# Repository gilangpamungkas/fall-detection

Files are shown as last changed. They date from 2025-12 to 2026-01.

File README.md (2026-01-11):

# 🛡️ mmWave-Based Indoor Fall Detection System  
**CASA0016 – Making, Designing & Building Connected Sensor Systems**

An edge-based, privacy-preserving indoor fall detection prototype using a 60 GHz mmWave radar sensor, MQTT communication, and real-time WhatsApp alerts.

---

## 📌 Project Overview

Falls are a major cause of injury among older adults, particularly in indoor environments where rapid detection is critical.  
This project designs, builds, and evaluates an **indoor fall detection prototype** using a **60 GHz mmWave radar sensor** integrated with an **ESP32-based microcontroller**.

Unlike vision-based approaches, the system enables **continuous, non-contact monitoring** while preserving user privacy. Fall detection is performed locally using embedded radar firmware, with **edge-based event handling** triggering both local alerts and remote notifications.

⚠️ **Disclaimer:** This prototype is not a medical device and is intended for educational and exploratory purposes only.

---

## 🧠 Key Capabilities

- Privacy-preserving, non-contact sensing  
- Edge-based fall detection (no raw motion data transmitted)  
- Immediate local alerts (RGB LED + buzzer)  
- Remote notifications via WhatsApp  
- Lightweight IoT communication using MQTT  
- Designed for continuous indoor deployment  

---

## 🏗️ System Architecture

The system follows an **edge-centric, event-driven architecture**:

<p align="center">
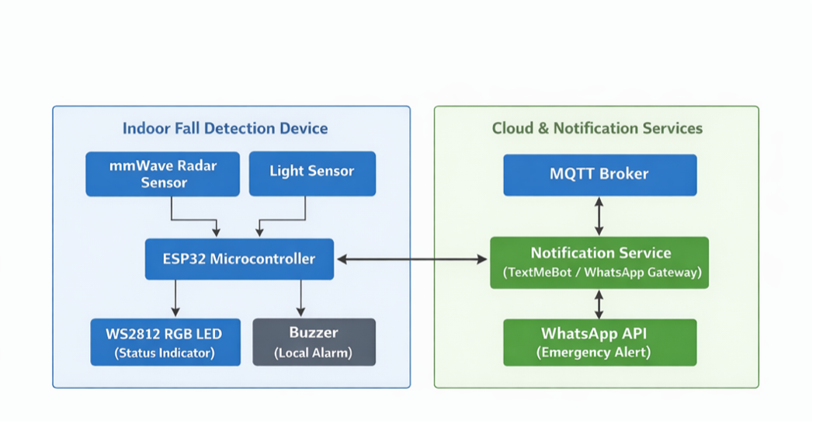
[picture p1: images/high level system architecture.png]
Figure 1. high level system architecture
  
</p>

<p align="center"><em>Figure 1. high level system architecture</em></p>

### 1️⃣ Sensing & Classification (Edge)
- 60 GHz mmWave radar performs embedded fall detection
- Abstracted states: `no presence`, `presence`, `fall`
- No transmission of raw sensor data

### 2️⃣ Local Feedback
- RGB LED indicates system state
- Audible buzzer activates on confirmed fall events

### 3️⃣ Communication & Alerts
- MQTT publishes lightweight status messages
- WhatsApp alerts sent via HTTP API
- NTP time synchronisation for alert timestamps
- One-time alert logic prevents notification flooding

---

## 🔩 Hardware Components

| Component | Description |
|---|---|
| MR60FDA2 | 60 GHz mmWave fall detection module |
| XIAO ESP32C6 | Embedded microcontroller with Wi-Fi |
| RGB LED (WS2812B) | Visual system state indication |
| Grove Buzzer | Audible fall alert |
| BH1750 | Ambient light sensor (contextual only) |
| Power Supply | 5 V USB (always-on indoor deployment) |

**Mounting:** Ceiling-mounted at ~2.5 m in a residential room.

<p align="center">
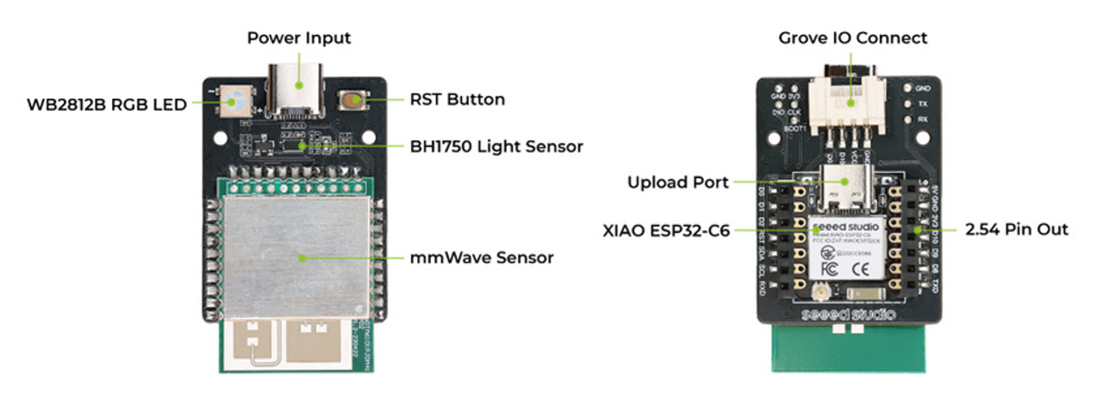
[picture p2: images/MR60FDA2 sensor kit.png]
Figure 2. MR60FDA2 sensor kit
  
</p>

<p align="center"><em>Figure 2. MR60FDA2 sensor kit</em></p>

---

## 🧱 Physical Implementation

**Figure:** Physical implementation of the prototype  
- **(a)** Fusion 360 enclosure design  
- **(b)** 3D-printed enclosure with device placement  
- **(c)** Grove buzzer for audible alerts  

<p align="center">
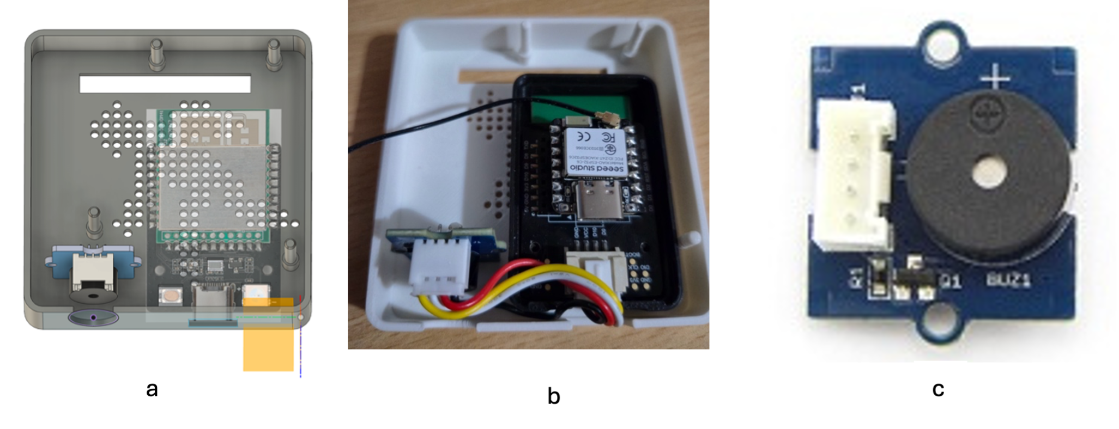
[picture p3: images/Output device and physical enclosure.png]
Figure 3. Physical implementation of the prototype: (a) Fusion 360 enclosure design, (b) 3D-printed enclosure with device placement, (c) Grove buzzer for audible alerts
  
</p>

<p align="center"><em>Figure 3. Physical implementation of the prototype: (a) Fusion 360 enclosure design, (b) 3D-printed enclosure with device placement, (c) Grove buzzer for audible alerts</em></p>

📂 Fusion 360 files of enclosure are available in `/enclosure/`.

---

## 💻 Software Stack

- Arduino IDE  
- Seeed Arduino mmWave Library  
- Adafruit NeoPixel Library  
- WiFi & PubSubClient (MQTT)  
- HTTPClient (WhatsApp API)  
- NTP time synchronisation  

Core logic is implemented in a **single Arduino sketch** (/fall_detection_v2.ino) for clarity and reproducibility.

---

## 🔁 Reproducibility Guide

### 🔌 Wiring

Most sensing and processing components are **integrated within the MR60FDA2 kit**.  
External wiring is limited to:

- Grove Buzzer  
- Power supply (USB)

<p align="center">
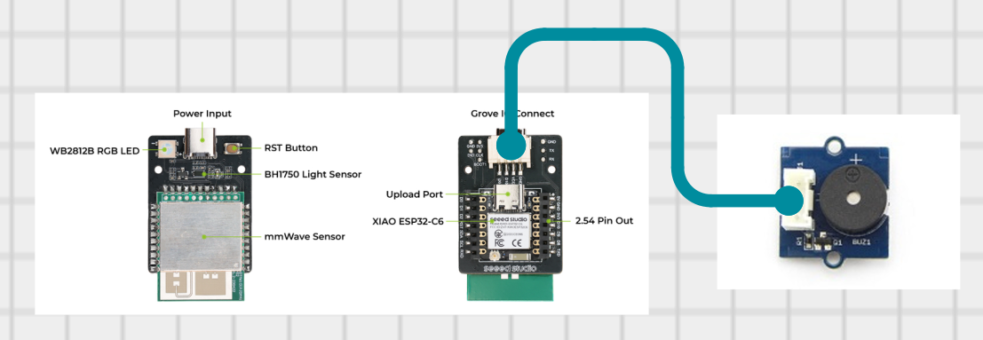
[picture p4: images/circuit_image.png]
Figure 4. Wiring Diagram
  
</p>

<p align="center"><em>Figure 4. Wiring Diagram</em></p>

---

### 📍 Pin Mapping

| Component | Pin |
|---|-----|
| Grove Buzzer | GPIO (external) |
| RGB LED | Integrated |
| mmWave Radar | Integrated |
| BH1750 | Integrated |

---

### ⚙️ Installation Parameters

The following parameters are configured based on the official MR60FDA2 mmWave sensor guidelines and directly influence fall detection behaviour:

| Parameter | Typical Value | Description |
|---|---|---|
| Mounting height | ~2.5 m | Recommended ceiling-mounted height for reliable top-down fall detection coverage |
| Detection threshold | Configurable | Vertical displacement threshold used by the embedded fall detection firmware |
| Sensitivity | Medium | Controls radar responsiveness to motion intensity |
| Alert mode | One-time per fall | Prevents repeated notifications from a single detected fall event |

These parameters were tuned to balance detection reliability and false-positive reduction in a residential indoor environment.  
See: *Getting Started with MR60FDA2 mmWave Kit* (Seeed Studio, 2025).

---

### ▶️ Setup Order

1. Mount the device on the ceiling at approximately 2.5 m.
2. Power the system via a 5 V USB supply.
3. Configure Wi-Fi credentials in the Arduino sketch.
4. Configure MQTT broker address and topic settings.
5. Configure WhatsApp notification parameters (TextMeBot API key and chat ID).
6. Set installation parameters (mounting height, detection threshold, sensitivity).
7. Upload the firmware to the ESP32C6.
8. Deploy the system and observe LED state indicators.
9. Test fall detection scenarios and verify local and remote alerts.

---

### 📲 WhatsApp Alert Configuration

Remote fall alerts are delivered using the **TextMeBot WhatsApp API**, a lightweight HTTP-based service that enables WhatsApp message delivery from embedded devices without requiring a dedicated messaging server.

When a fall event is detected, the ESP32 sends an HTTP GET request to the TextMeBot API endpoint, which forwards the alert message to a configured WhatsApp number.

#### 🔑 API Key and Recipient Configuration

To enable WhatsApp notifications, users must obtain a personal **TextMeBot API key** and associate it with their WhatsApp number following the instructions provided by the service. These credentials are user-specific and are therefore not included in this repository.

The following parameters must be configured directly in the Arduino sketch (`.ino` file):

```cpp
// --- WhatsApp (TextMeBot) Configuration ---
// Replace with your own API key and recipient number
const char* TEXTMEBOT_API_KEY = "YOUR_API_KEY";
const char* TEXTMEBOT_RECIPIENT = "+441234567890";  // WhatsApp number including country code
🌐 Message Delivery Mechanism
When a fall is detected, the firmware constructs and sends an HTTP request of the following form:

arduino
Copy code
https://api.textmebot.com/web_send.php?apikey=YOUR_API_KEY&recipient=PHONE_NUMBER&text=MESSAGE
The request is sent using the ESP32 HTTP client library. Message content is URL-encoded to ensure safe transmission. A timestamp obtained via NTP synchronisation is appended to the message to provide temporal context.

🔒 Rate Limiting and Safety
To prevent alert flooding, the system implements a one-time notification mechanism, ensuring that only a single WhatsApp alert is sent per detected fall event until the system state resets. This behaviour improves usability and reflects realistic deployment requirements for indoor safety monitoring systems.
```
---

## 🧪 Evaluation Summary

Testing was conducted in a **room-scale indoor environment** under three scenarios:

1. No occupant present  
2. Normal movement (walking, standing, sitting)  
3. Simulated fall events  

### Key Observations
- Immediate fall detection and alert triggering  
- Stable MQTT publishing  
- No false positives during normal movement  
- Sensitivity to threshold configuration  
- Limited discrimination between falls and slow postural transitions  

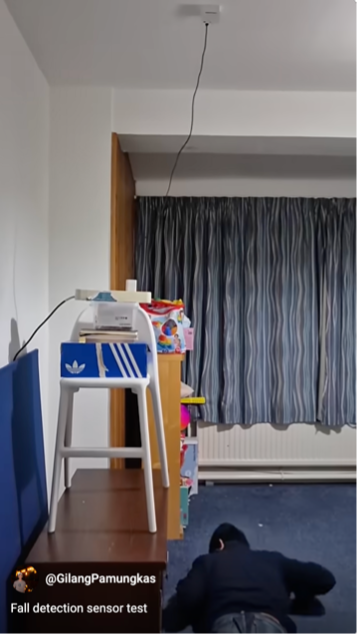
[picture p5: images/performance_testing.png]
Demo Video (https://www.youtube.com/shorts/zDeqPK8EPvs)
🚀 See the project come to life! Watch the demo on Youtube here: 

---

## 🔍 Reflection & Limitations

- Detection behaviour is sensitive to threshold configuration  
- Proprietary radar firmware limits access to raw motion data  
- The system cannot reliably distinguish intentional lying from real falls  
- Design constraints reflect real-world IoT deployment trade-offs  

The project intentionally focuses on **system-level design**, prioritising:
- deployment realism  
- privacy preservation  
- robustness  
- reproducibility  

---

## 🚀 Future Work

- Learning-based fall classification using temporal motion features  
- Access to raw mmWave data for improved semantic accuracy  
- Multi-sensor fusion (e.g. inertial validation)  
- Battery-powered operation  
- Multi-room monitoring dashboard  

---

## 📂 Repository Structure

```
fall-detection/
├── enclosure/ # Enclosure design files (Fusion 360 & STL)
├── images/ # Photos and diagrams used in README
├── README.md # Main project documentation
├── arduino_secrets_template.h # Template for API keys and sensitive config
├── fall_detection_v2.ino # Main Arduino firmware sketch
├── LICENSE.txt # MIT License

```
---

## 📄 Coursework Context

- **Module:** CASA0016 – Making, Designing & Building Connected Sensor Systems  
- **Institution:** UCL Centre for Advanced Spatial Analysis, MSc Connected Environments 
- **Author:** Gilang Pamungkas  
- **Date:** December 2025  

📘 The full technical report accompanies this repository.

---

## 📚 References

Huh, H., Jeong, I., Lee, A., Lee, S. and Shin, Y.-S. (2025). Leveraging falling acceleration and body part clustering for physics-based human fall detection with millimeter wave radar. *Engineering Applications of Artificial Intelligence*, 159, 111500.

Seeed Studio (2025). *Getting Started with MR60FDA2 mmWave Kit*. Available at: https://wiki.seeedstudio.com/getting_started_with_mr60fda2_mmwave_kit (Accessed: 30 December 2025).

Shi, W., Cao, J., Zhang, Q., Li, Y. and Xu, L. (2016). Edge computing: Vision and challenges. *IEEE Internet of Things Journal*, 3(5), pp. 637–646.

Wang, Z., Yan, G., Yang, X., Zhao, X., Li, X. and Chai, M. (2023). Research on the fall detection method based on millimeter-wave radar. In: *Proceedings of the 5th International Conference on Intelligent Control, Measurement and Signal Processing (ICMSP 2023)*, pp. 139–142.

World Health Organization (2007). *WHO Global Report on Falls Prevention in Older Age*. Geneva: World Health Organization.

World Health Organization (2023). *Ageing and Health*. Available at: https://www.who.int/news-room/fact-sheets/detail/ageing-and-health (Accessed: 24 December 2025).

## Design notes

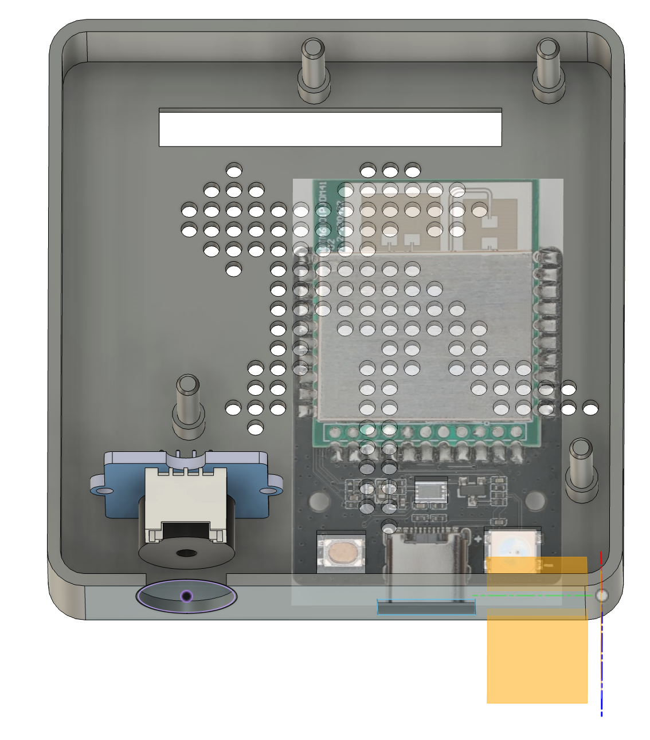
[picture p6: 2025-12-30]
images/sensor design.png

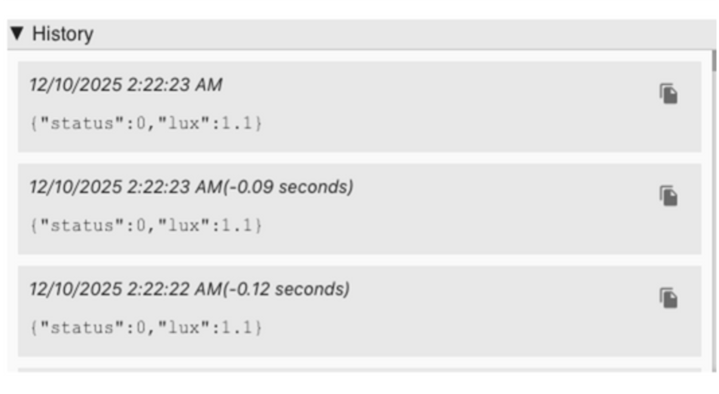
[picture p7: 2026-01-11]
images/sample mqtt messages.png

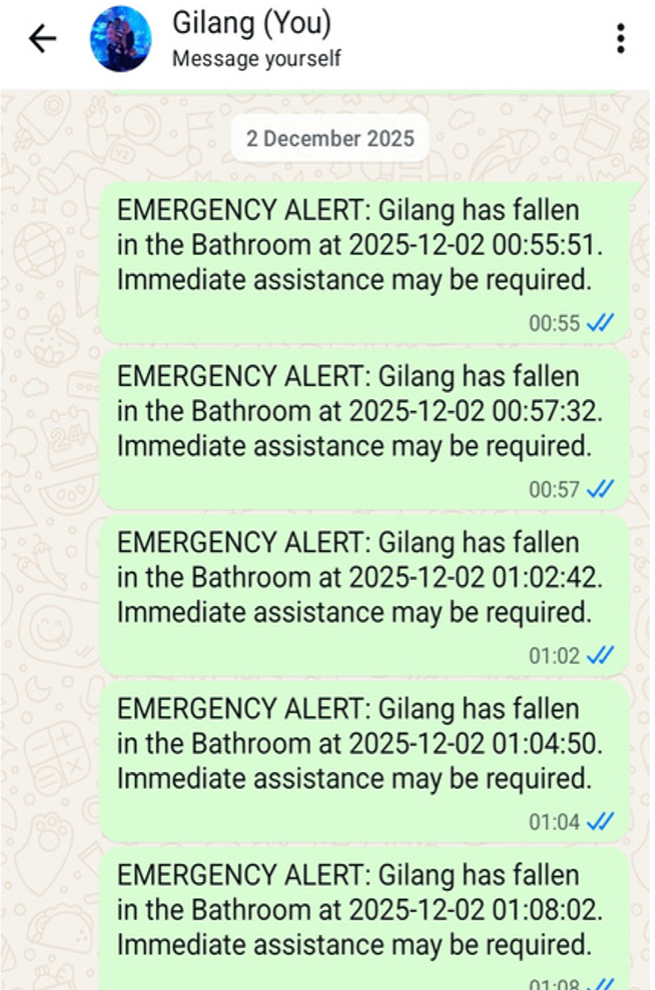
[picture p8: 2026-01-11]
images/sample of whatsapp alert.png

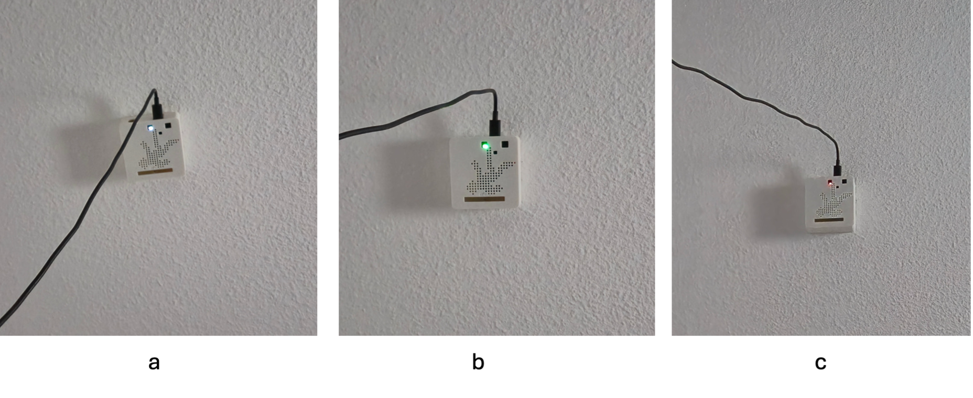
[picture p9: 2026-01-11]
images/LED colour representation.png

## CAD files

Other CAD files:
enclosure/enclosure_bottom_side.f3d
enclosure/enclosure_top_side.f3d

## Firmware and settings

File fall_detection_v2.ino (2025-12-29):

/**
 * CASA0016 — mmWave-Based Indoor Fall Detection System
 * University College London | Making, Designing & Building Connected Sensor Systems
 *
 * This sketch implements an edge-based indoor fall detection prototype using:
 * - MR60FDA2 60 GHz mmWave radar sensor (proprietary fall detection firmware)
 * - Seeed Studio XIAO ESP32C6 microcontroller
 * - WS2812 RGB LED and piezo buzzer for local feedback
 * - MQTT for lightweight status publishing
 * - WhatsApp alerts via TextMeBot HTTP API
 *
 * Reproducibility & Configuration
 * -------------------------------
 * This project requires a user-provided configuration file:
 *   arduino_secrets.h
 *
 * A template file:
 *   arduino_secrets_template.h
 * is included in this repository. To reproduce the system:
 * 1. Copy the template file
 * 2. Rename it to arduino_secrets.h
 * 3. Populate it with your own credentials (Wi-Fi, MQTT, API keys)
 *
 * IMPORTANT:
 * - Do NOT commit arduino_secrets.h to version control
 * - This prototype is for academic and exploratory use only
 * - It is NOT a medical or safety-certified device
 *
 * Design Notes
 * ------------
 * - Fall detection logic runs in closed, vendor-provided firmware
 * - This sketch reads high-level detection states only
 * - Alert logic is event-driven and rate-limited (one alert per fall)
 */

#include <Arduino.h>
#include <Adafruit_NeoPixel.h>
#include <hp_BH1750.h>
#include "Seeed_Arduino_mmWave.h"

#include <WiFi.h>
#include <PubSubClient.h>
#include <HTTPClient.h>
#include <time.h>

#include "arduino_secrets.h"  // User-provided secrets (see template)

/* ============================= Network clients ============================= */
WiFiClient wifiClient;
PubSubClient client(wifiClient);

/* =============================== GPIO settings ============================= */
#define BUZZER_PIN D0
#define LIGHT_GPIO D0  // Kept unchanged (forced LOW in loop; BH1750 used for logging only)

/* =============================== MQTT settings ============================= */
String mqtt_topic = MQTT_TOPIC;   // from arduino_secrets.h
static const char* MQTT_CLIENT = MQTT_CLIENT_ID;

/* ============================ mmWave sensor config ========================== */
#ifdef ESP32
  #include <HardwareSerial.h>
  HardwareSerial mmwaveSerial(0);     // UART channel used by mmWave module (ESP32)
#else
  #define mmwaveSerial Serial1
#endif

SEEED_MR60FDA2 mmWave;

// Tuneable parameters (match physical installation)
uint32_t sensitivity = 15;            // Higher values can increase responsiveness (and false alarms)
float height = 2.5f;                  // Mount height (metres)
float threshold = 0.6f;               // Detection threshold (tune carefully)

// Returned radar parameters (optional debug)
float rect_XL, rect_XR, rect_ZF, rect_ZB;

/* ============================ Light sensor + LED ============================ */
hp_BH1750 BH1750;
Adafruit_NeoPixel pixels(1, D1, NEO_GRB + NEO_KHZ800);

/* ============================== System state =============================== */
typedef enum {
  EXIST_PEOPLE = 0,
  NO_PEOPLE    = 1,
  PEOPLE_FALL  = 2,
} MMMWAVE_STATUS;

MMMWAVE_STATUS status = NO_PEOPLE;
MMMWAVE_STATUS last_status = NO_PEOPLE;

float lux = 100.0f;
bool doingFallBuzz = false;

/* =============================== Wi-Fi helper ============================== */
/**
 * Connects to the first available Wi-Fi network listed in arduino_secrets.h.
 * Retries each SSID for ~10 seconds.
 */
void startWifi() {
  Serial.println("Starting WiFi...");

  WiFi.mode(WIFI_STA);
  WiFi.disconnect(true);
  delay(200);

  for (int i = 0; i < numNetworks; i++) {
    Serial.print("Trying SSID: ");
    Serial.println(ssids[i]);

    WiFi.begin(ssids[i], passwords[i]);
    const unsigned long startAttempt = millis();

    while (WiFi.status() != WL_CONNECTED && (millis() - startAttempt) < 10000) {
      Serial.print(".");
      delay(500);
    }

    if (WiFi.status() == WL_CONNECTED) {
      Serial.println("\nWiFi connected!");
      Serial.print("IP: ");
      Serial.println(WiFi.localIP());
      return;
    }

    Serial.println("\nFailed. Trying next...");
    WiFi.disconnect(true);
    delay(200);
  }

  Serial.println("Could not connect to any WiFi.");
}

/* =============================== MQTT helper =============================== */
/**
 * Connects/reconnects to MQTT broker using credentials from arduino_secrets.h.
 * Blocks until connected.
 */
void reconnectMQTT() {
  while (!client.connected()) {
    Serial.print("Connecting to MQTT... ");
    if (client.connect(MQTT_CLIENT, MQTT_USER, MQTT_PASS)) {
      Serial.println("connected.");
    } else {
      Serial.print("failed, rc=");
      Serial.print(client.state());
      Serial.println(" retrying in 5 seconds");
      delay(5000);
    }
  }
}

/* ============================ WhatsApp notification ========================= */
/**
 * Sends an alert message via TextMeBot (WhatsApp).
 * Secrets (recipient, API key, base URL, message prefix/suffix) live in arduino_secrets.h.
 */
void sendWhatsAppAlert() {
  if (WiFi.status() != WL_CONNECTED) {
    Serial.println("[WhatsApp] WiFi not connected!");
    return;
  }

  struct tm timeinfo;
  if (!getLocalTime(&timeinfo)) {
    Serial.println("[WhatsApp] Failed to obtain time!");
    return;
  }

  char timeString[40];
  strftime(timeString, sizeof(timeString), "%Y-%m-%d %H:%M:%S", &timeinfo);

  // Build URL-encoded message using configurable prefix/suffix
  String message = WHATSAPP_MESSAGE_PREFIX;
  message += String(timeString);
  message += WHATSAPP_MESSAGE_SUFFIX;

  // Minimal extra encoding (kept consistent with your original behaviour)
  message.replace(" ", "%20");
  message.replace(":", "%3A");

  // Build request URL from secrets
  String url = String(TEXTMEBOT_BASE_URL);
  url += "recipient=" + String(TEXTMEBOT_RECIPIENT);
  url += "&apikey=" + String(TEXTMEBOT_APIKEY);
  url += "&text=" + message;

  Serial.println("[WhatsApp] Sending alert...");
  // Note: printing the full URL may reveal secrets in Serial logs.
  // Uncomment only when debugging locally.
  // Serial.println(url);

  HTTPClient http;
  http.begin(url);
  const int httpCode = http.GET();

  if (httpCode > 0) {
    Serial.printf("[WhatsApp] Response: %d\n", httpCode);
    Serial.println(http.getString());
  } else {
    Serial.printf("[WhatsApp] Error: %s\n", http.errorToString(httpCode).c_str());
  }

  http.end();
}

/* =========================== Local feedback helpers ========================= */
void updateLedForStatus(MMMWAVE_STATUS s) {
  if (s == NO_PEOPLE)    pixels.setPixelColor(0, pixels.Color(0, 0, 255));   // Blue
  if (s == EXIST_PEOPLE) pixels.setPixelColor(0, pixels.Color(0, 255, 0));   // Green
  if (s == PEOPLE_FALL)  pixels.setPixelColor(0, pixels.Color(255, 0, 0));   // Red
  pixels.show();
}

void startFallBuzzer() {
  tone(BUZZER_PIN, 700);
  doingFallBuzz = true;
}

void stopFallBuzzer() {
  noTone(BUZZER_PIN);
  doingFallBuzz = false;
}

/* =================================== Setup ================================== */
void setup() {
  Serial.begin(115200);

  // ---- mmWave module init + configuration ----
  mmWave.begin(&mmwaveSerial);
  mmWave.setUserLog(0);
  mmWave.setInstallationHeight(height);
  mmWave.setThreshold(threshold);
  mmWave.setSensitivity(sensitivity);
  mmWave.getRadarParameters(height, threshold, sensitivity, rect_XL, rect_XR, rect_ZF, rect_ZB);

  // ---- Buzzer ----
  pinMode(BUZZER_PIN, OUTPUT);
  noTone(BUZZER_PIN);

  // ---- Network ----
  startWifi();
  client.setServer(MQTT_SERVER, MQTT_PORT);
  reconnectMQTT();

  // ---- NTP time ----
  // Offsets (including daylight) are configured in arduino_secrets.h
  configTime(NTP_GMT_OFFSET_SEC, NTP_DAYLIGHT_OFFSET_SEC, "pool.ntp.org", "time.nist.gov");

  // ---- LED ----
  pixels.begin();
  pixels.clear();
  pixels.setBrightness(8);
  pixels.setPixelColor(0, pixels.Color(125, 125, 125));  // boot indicator
  pixels.show();

  // ---- BH1750 (context only) ----
  BH1750.begin(BH1750_TO_GROUND);
  BH1750.calibrateTiming();
  BH1750.start(BH1750_QUALITY_HIGH2, 254);

  // ---- LIGHT_GPIO ----
  pinMode(LIGHT_GPIO, OUTPUT);
}

/* ==================================== Loop ================================== */
void loop() {
  // Maintain connectivity
  if (WiFi.status() != WL_CONNECTED) startWifi();
  if (!client.connected()) reconnectMQTT();
  client.loop();

  // -------------------- Read mmWave abstracted states --------------------
  if (mmWave.update(100)) {
    bool is_human = false;
    bool is_fall = false;

    mmWave.getHuman(is_human);
    mmWave.getFall(is_fall);

    if (!is_human && !is_fall) status = NO_PEOPLE;
    else if (is_fall)          status = PEOPLE_FALL;
    else                       status = EXIST_PEOPLE;
  }

  // ---------------------------- Serial logging ---------------------------
  switch (status) {
    case NO_PEOPLE:    Serial.println("Waiting for people"); break;
    case EXIST_PEOPLE: Serial.println("PEOPLE detected");    break;
    case PEOPLE_FALL:  Serial.println("FALL detected");      break;
    default: break;
  }

  // ------------------ One-time WhatsApp alert per fall -------------------
  static bool fallAlertSent = false;
  if (status == PEOPLE_FALL && !fallAlertSent) {
    sendWhatsAppAlert();
    fallAlertSent = true;
  }
  if (status != PEOPLE_FALL) {
    fallAlertSent = false;
  }

  // ------------------ Update LED + buzzer on state change ----------------
  if (status != last_status) {
    updateLedForStatus(status);

    if (status == PEOPLE_FALL) startFallBuzzer();
    if (status != PEOPLE_FALL && doingFallBuzz) stopFallBuzzer();

    last_status = status;
  }

  // ---------------------- Read BH1750 (informational) ---------------------
  if (BH1750.hasValue()) {
    lux = BH1750.getLux();
    BH1750.start(BH1750_QUALITY_HIGH2, 254);
  }
  Serial.print("LUX: ");
  Serial.println(lux);

  // Keep original behaviour: no darkness-triggered action
  digitalWrite(LIGHT_GPIO, LOW);

  // --------------------------- MQTT status publish ------------------------
  char payload[64];
  snprintf(payload, sizeof(payload), "{\"status\":%d,\"lux\":%.1f}", status, lux);
  client.publish(mqtt_topic.c_str(), payload);
}

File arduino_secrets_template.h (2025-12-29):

#pragma once
/**
 * arduino_secrets_template.h (SAFE TO COMMIT)
 *
 * HOW TO USE
 * 1) Copy this file and rename the copy to: arduino_secrets.h
 * 2) Fill in your own Wi-Fi / MQTT / WhatsApp credentials
 * 3) Keep arduino_secrets.h PRIVATE (add to .gitignore)
 *
 * NOTE
 * - This template contains placeholders only.
 * - Do NOT commit real credentials to GitHub.
 */

/* ================================ Wi-Fi ================================== */
// Multiple networks are supported; the sketch will try them in order.
const int numNetworks = 1;

const char* ssids[] = {
  "YOUR_WIFI_SSID"
};

const char* passwords[] = {
  "YOUR_WIFI_PASSWORD"
};

/* ================================= MQTT ================================== */
#define MQTT_SERVER    "YOUR_MQTT_BROKER"
#define MQTT_PORT      1883

#define MQTT_USER      "YOUR_MQTT_USERNAME"
#define MQTT_PASS      "YOUR_MQTT_PASSWORD"

#define MQTT_CLIENT_ID "MMWAVE01"
#define MQTT_TOPIC     "student/CASA0016/gilangpamungkas"

/* ============================== NTP / TIME ================================ */
// Time is used to timestamp WhatsApp alerts.
//
// UK winter (GMT):  0, 0
// UK summer (BST):  3600, 0
#define NTP_GMT_OFFSET_SEC       0
#define NTP_DAYLIGHT_OFFSET_SEC  0

/* ========================== TextMeBot (WhatsApp) ========================== */
#define TEXTMEBOT_BASE_URL  "http://api.textmebot.com/send.php?"

// Recipient phone number (URL-encoded, include country code)
#define TEXTMEBOT_RECIPIENT "%2B1234567890"

// API key for TextMeBot
#define TEXTMEBOT_APIKEY    "YOUR_TEXTMEBOT_API_KEY"

// Message parts (URL-encoded recommended)
#define WHATSAPP_MESSAGE_PREFIX  "EMERGENCY%20ALERT%3A%20Fall%20detected%20at%20"
#define WHATSAPP_MESSAGE_SUFFIX  ".%20Immediate%20assistance%20may%20be%20required."

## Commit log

2025-12-29 enclosure fusion file
    [enclosure_bottom_side.f3d, enclosure_top_side.f3d]
2026-01-11 enclosure edit
    [enclosure_bottom_side.f3d, enclosure_top_side.f3d]
2026-01-11 wiring diagram
